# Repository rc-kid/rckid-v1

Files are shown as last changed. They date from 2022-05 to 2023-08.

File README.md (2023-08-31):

# RCkid

Handheld device mostly for kids that works as a retro games player, remote control for lego models and other stuff, walkie talkie, and a simple music/video player. Based on Rpi Zero 2W, ATTiny and NRF24L01P+ with a 320x240 SPI display, a selection of input controls (ABXY, DPAD, Thumbstick, Sel, Start, shoulder buttons, dedicated volume control buttons and a Home button), rumbler, light sensor, RGB torch and a custom software tailored towards the needs of the little ones. 

This is the main repository of the project containing all the necessary information to build the _RCkid_ itself and the remotely controlled devices.

## Overview

The _RCkid_ uses the RPi to run all the user interactive software, libretro via retropie to run emulated old school games and other software. The RPi is connected to digital buttons (ABXY, L, R, Volume) via gpio pins, to the display (`ILI9341`) with `SPI0` and to the NRF Radio via `SPI1`. `I2C` bus connects to the accelerometer, light sensor and the `ATTiny`. 

The `ATTiny` then manages the analog inputs (joystick, voltages, temperatures), multiplexed buttons (Dpad, Select & Start) and the Home/Power button. It is also responsible for the rumbler and the RGB LED as well as charging, battery management and a real-time clock. 

## Developing

> For building the RaspberryPi SD Card image see the [IMAGE.md](sd/IMAGE.md). This section deals with the active development setup. It has been tested on Windows 11, WSL Ubuntu 20. 

    sudo apt-get install vlc alsa-utils
    git clone https://github.com/zduka/rckid-raylib.git
    cd rckid-raylib/src
    make PLATFORM=PLATFORM_DESKTOP
    cd ../..
    git clone https://github.com/zduka/rckid.git
    mkdir rckid/build
    cd rckid/build
    cmake ..

### AVR UPDI Programmer

Serial UPDI is used, more details [here](https://github.com/SpenceKonde/AVR-Guidance/blob/master/UPDI/jtag2updi.md). I am using CH340 based one with a diode (BAT-60J) and internal 1k5 resistor on TX line. 

> Note that when using an adapter with a RX-line LED, such as most CH340 based ones, the LED must be removed or the programmer will *not* work. This is somewhat burried in the original document and it took me a while to realize this. 

There seems to be a possibility of building a high voltage UPDI programmer, details [here](http://www.technoblogy.com/show?48MP).

## Basic Operation

The `fbcp-ili9341` runs in its own process and is responsible for displaying the contents of the framebuffer on the SPI display.

> The display will freeze if someone changes the display properties. This seems to not happen if all apps run as `pi` (no root), but might be investigated further. 

The `rckid` app controls the UI, communicates with the AVR and creates and manages the virtual joystick and keyboard that is used to control the external applications. It uses a patched version of [raylib](https://github.com/zduka/rckid-raylib) that displays the UI at a level that will display itself over the 3rd party apps for videos and games. 

`vlc` and `retroarch` are used for playing videos and games respectively. They are launched by the ui and then controlled via the libevdev virtual gamepad and keyboard. 

- [VideoCore APIs](https://elinux.org/Raspberry_Pi_VideoCore_APIs)
- [DismpanX header](https://github.com/raspberrypi/userland/blob/master/interface/vmcs_host/vc_dispmanx.h)
- [DispmanX example](https://github.com/raspberrypi/firmware/blob/master/opt/vc/src/hello_pi/hello_dispmanx/dispmanx.c)
- [RaspiDMX tools](https://github.com/AndrewFromMelbourne/raspidmx/blob/master/common/imageLayer.c)

### Prepare the RPi image

To build on Raspberry pi, create SD card image according to `sd/IMAGE.md`. This also installs all the prerequisites for building the rpi app and flashing the AVR. 

> As building on rpi is clumsy for development, most of rcboy can be developed on a normal computer (tested on Windows 11 WSL) and then uploaded to the rpi over WiFi. The repository contains tasks and build scripts necessary for such a setup using Visual Studio Code and can be easily adapted to different IDEs/editors.

### Flashing the AVR

When the RCBoy is assembled, the AVR chip is flashed via a custom I2C bootloader (the UPDI voltages would have to be translated otherwise, which is painful as the AVR runs on higher voltage than RPi). The RPi itself can be used to flash the AVR chip before soldered to the board by making a simple UPDI programmer from the serial port. After the bootloader is flashed, the RPi can be soldered to the board and the I2C programmer can be used for future updates. 

### Notes to Self 

- when stuff does not work, double and tripple check that all pins are properly soldered. Obviously no shorts, but weak bonds will result is horrible noise and/or non-functional elements
- a variant of the above, when soldering multiple PCBs together via holes, be extra sure that all PCBs actually have proper contact

## RCKid folder structure

    /rckid
        /music
        /videos
        /games
        /screenshots
        /images
        /recorder
        /saves

# Notes

https://www.flaticon.com/

<div>Icons made by <a href="https://www.flaticon.com/authors/alfredo-hernandez" title="Alfredo Hernandez">Alfredo Hernandez</a> from <a href="https://www.flaticon.com/" title="Flaticon">www.flaticon.com</a></div>
<div>Icons made by <a href="https://www.flaticon.com/authors/pixel-perfect" title="Pixel perfect">Pixel perfect</a> from <a href="https://www.flaticon.com/" title="Flaticon">www.flaticon.com</a></div>
<div>Icons made by <a href="https://www.flaticon.com/authors/vectors-market" title="Vectors Market">Vectors Market</a> from <a href="https://www.flaticon.com/" title="Flaticon">www.flaticon.com</a></div>
<div>Icons made by <a href="https://www.flaticon.com/authors/srip" title="srip">srip</a> from <a href="https://www.flaticon.com/" title="Flaticon">www.flaticon.com</a></div>
<div>Icons made by <a href="https://www.flaticon.com/authors/monkik" title="monkik">monkik</a> from <a href="https://www.flaticon.com/" title="Flaticon">www.flaticon.com</a></div>
<div>Icons made by <a href="https://www.flaticon.com/authors/aldo-cervantes" title="Aldo Cervantes">Aldo Cervantes</a> from <a href="https://www.flaticon.com/" title="Flaticon">www.flaticon.com</a></div>
<div>Icons made by <a href="https://www.freepik.com" title="Freepik">Freepik</a> from <a href="https://www.flaticon.com/" title="Flaticon">www.flaticon.com</a></div>
<div>Icons made by <a href="https://www.flaticon.com/authors/smashicons" title="Smashicons">Smashicons</a> from <a href="https://www.flaticon.com/" title="Flaticon">www.flaticon.com</a></div>
<div>Icons made by <a href="https://www.flaticon.com/authors/umeicon" title="Umeicon">Umeicon</a> from <a href="https://www.flaticon.com/" title="Flaticon">www.flaticon.com</a></div>
<div>Icons made by <a href="https://www.flaticon.com/authors/bukeicon" title="bukeicon">bukeicon</a> from <a href="https://www.flaticon.com/" title="Flaticon">www.flaticon.com</a></div>
<div>Icons made by <a href="https://www.flaticon.com/authors/good-ware" title="Good Ware">Good Ware</a> from <a href="https://www.flaticon.com/" title="Flaticon">www.flaticon.com</a></div>
<div>Icons made by <a href="https://www.flaticon.com/authors/apien" title="apien">apien</a> from <a href="https://www.flaticon.com/" title="Flaticon">www.flaticon.com</a></div>
<div>Icons made by <a href="https://www.flaticon.com/authors/luvdat" title="Luvdat">Luvdat</a> from <a href="https://www.flaticon.com/" title="Flaticon">www.flaticon.com</a></div>
<div>Icons made by <a href="https://www.flaticon.com/authors/surang" title="surang">surang</a> from <a href="https://www.flaticon.com/" title="Flaticon">www.flaticon.com</a></div>
<div>Icons made by <a href="https://www.flaticon.com/authors/chahir" title="chahir">chahir</a> from <a href="https://www.flaticon.com/" title="Flaticon">www.flaticon.com</a></div>

https://www.vecteezy.com/vector-art/4998362-seamless-rainbow-pattern-with-unicorns-hearts-crowns-and-stars-on-a-dark-background

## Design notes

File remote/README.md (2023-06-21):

# RCKid Remote Protocol

A simple and extensible protocol that allows the RCKid to use its onboard NRF radio to remotely control various devices. The RCKid acts as a _remote_ that can control an arbitrary number of _devices_. Each device has a number of _channels_ into which all the device's functionality has to be encoded. The remote protocol supports pairing, querying devices and their channel capabilities and so on. 

> Note that the protocol is very simple and its main purpose is *not* security. 

## Channels

A client device is described by a list of channels. Each channel has a specific type and consists of the following distinct parts:

- _control_, which is information the remote communicates regularly to the device that alters the state of the channel (such as motor speed)
- _feedback_, which is information the device communicates to the remote, such as current consumption
- _config_, which consists of channel configuration that is not expected to be changed once the remote and the device are paired, such as the motor's current limit

Each part of the channel can be empty, depending on the channel type. Channels are identified by numbers from `1` to `255` inclusive. The following channel types are supported:

### Motor channel

The motor channel provides control for single DC brushed motor attached to an H bridge. It consists

### CustomIO

A configurable channel that can fit multiple purposes. Corresponds to a single wire and various digital/analog functions it may have, namely:

Mode              | Control   | Feedback | Config
------------------|-----------|----------| -------------
Digital Out       | 0/1       |          | 00
Digital In        |           | 0/1      | 01
Analog Out (DAC)  | 0 - 255   |          | 02
Analog In (ADC)   |           | 0 - 255  | 03
PWM               | 0 - 255   |          | 04
Servo             | 0 - 65535 |          | 05 iiii xxxx
Tone              | 0 - 65535 |          | 06

### ToneEffect

### RGB Strip

The RGB strip channel is designed to configure and control a strip of RGB colors such as neopixels. The config part of the strip is the index of the first RGB channel specifying the color and the length of the strip. The length of the strip should not exceed the number of RGB colors available. The is no feedback and the channel control is the state of the strip, which can be one of:

ID   | Meaning
-----|-------------------
`00` | Manual control - the strip will display exactly the colors specified in the RGB channels
`..` | Effect - the number specifies which effect to use

### RGB Color

Single RGB color. Its control cosists of the three RGB bytes. No feedback or config is possible. The purpose of the RGB color channel is to simply hold memory for one neopixel. The device itself and the RGBStrip channel's config the determine which of these colors will be used. 

## Communication

## Commands

By default the remote sends the device channel control information and the device sends back the channel feedback info when there is change. Instead of sending directly the channel data, the remote may choose to send one of the predfined commands instead:

`00 00` - Heartbeat

`00 01 xx` - Read feedback of channel `xx`

`00 02 xx` - Read control of channel `xx`

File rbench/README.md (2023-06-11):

# A very simple Raylib benchmark

RPi Zero 2W Legacy:

    Initialized in 88
    Simple frame: 0
    1k textures: 32
    1k text: 81
    1k circles: 195
    1k rectangles: 7
    RT simple frame: 7
    RT 1k textures: 39
    RT 1k text: 80
    RT 1k circles: 210
    RT 1k rectangles: 15

RPi Zero 2W Bullseye:

> This is with X enabled and w/o the fbcp driver

    Initialized in 1326
    Simple frame: 2
    1k textures: 26
    1k text: 20
    1k circles: 38
    1k rectangles: 5
    RT simple frame: 2
    RT 1k textures: 28
    RT 1k text: 27
    RT 1k circles: 39
    RT 1k rectangles: 7

Intel HD630:

    Initialized in 150
    Simple frame: 0
    1k textures: 2
    1k text: 1
    1k circles: 1
    1k rectangles: 0
    RT simple frame: 0
    RT 1k textures: 1
    RT 1k text: 1
    RT 1k circles: 1
    RT 1k rectangles: 0

MESA on WSL SQ3:

    Initialized in 1379
    Simple frame: 3
    1k textures: 44
    1k text: 23
    1k circles: 28
    1k rectangles: 12
    RT simple frame: 2
    RT 1k textures: 43
    RT 1k text: 24
    RT 1k circles: 30
    RT 1k rectangles: 13

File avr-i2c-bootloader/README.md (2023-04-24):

# I2C Bootloader

A simple I2C bootloader that fits in 512 bytes. Both the bootloader and the programmer are pretty specific for the `rckid`, but minimal changes should make them generic. 

## Commands

Each I2C command is a single byte, optionally followed by an argument. The commands are designed in such way that they allow page-by-page writing and reading the memory so that the programmer can write and verify the memory contents with minimal AVR code required. 

`0x00 Reserved`

> Not used for anything. 

`0x01 RESET`

> Resets the chip.

`0x02 INFO`

> Updates the `State` object and sets the buffer address to it so that next reading from the device will return the state object itself. 

`0x03 WRITE_BUFFER`

> Writes data to the buffer. The command is only expected to be used after first setting the buffer address via `SET_ADDRESS` command. Using the flexible set address and the xmega core on Series-X ATTiny chips the same command can be used for writing both flash and eeprom. 

`0x04 WRITE_PAGE`

> Commits the page previously written to the appropriate memory (based on its mapped address). Sets the last error in `Status` info. 

`0x05 SET_ADDRESS`

> The command is followed by a 16bit unsigned which will be the new address for the buffer operations (write/read). By setting the address to the appropriate memory mapped locations for either flash or EEPROM memory the bootloader can simply write both. The same mechanism is also used to retrieve the `Status` object. 

## Bootloader

__Note that the UPDI programmer does not check if the chip is correct. If the chip specified in platformio and the actual chip do not match, the memory writes might not work even if everything else would (different memory will be written due to different page sizes) !!.__ 

The bootloader checks the status of the `AVR_IRQ` pin and if low, enters the bootloader mode. When high (i.e. pull-up enabled on the RPi side) starts the application. The bootloader is protected by a watchdog so that inactivity longer than a second will trigger reboot of the chip. The watchdog is reset after a command receive. 

When the bootloader is busy with a command it signals it by pulling the `AVR_IRQ` low, returning to input state when the command is executed, which allows fast programming times. 

To make programming observable, the bootloader also sets the display brightness to maximum. 

## Programmer

A simple i2c programmer is provided as well. Usage:

    i2c-programmer write HEX_FILE

`HEX_FILE` is path to the Intel HEX file that should be flashed to the chip. By default the programmer must be run by `root` to have access to the I2C and GPIO it requires to communicate with the AVR. The programmer can either time the commands by using the `AVR_IRQ` pin, or it can add a timeout to the commands when the `AVR_IRQ` connection is not available for whatever reason so that the bootloader can be used over I2C entirely. 

> Apart from basic flashing the programmer can do a bit more. Use the `--help` command for list of options. 

## Resources

- https://docs.platformio.org/en/latest/platforms/atmelavr.html#bootloader-programming
- https://www.microchip.com/en-us/application-notes/an2634

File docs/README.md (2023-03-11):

# RCKid Documentation

## MP3 Player / Audio Player

## Walkie-Talkie

The walkie talkie always listens and when a button is pressed reads the mic output and starts sending it immediately. When audio is received, stars playing it immediately. 

## Remote Control

Profiles (!) But how exactly?

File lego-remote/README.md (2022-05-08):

# LEGO Remote Controller for Picoboy

## Pairing

The control brick is very dumb and does not have any internal state (apart from its name) that would survive power cycle, all is managed by the remote. The handshake looks like this:

                              Controller | Remote
                         --------------- | --------------
                                         | L: (listen for new devices - optional) 
    B: broadcast its name on set channel | 
                                         | P1: send pairing info on set channel
                                         | (own name & channel, wait for ACK)
                                         |
            switch channel & wait for P2 | switch to channel, send P2, wait for ACK
                                         |
         (timeout 1 second, return to B) | (timeout 1 second, return to L, or P1)

While pairing the controller flashes red lights. When paired, blue is flashed. Upon pairing the remote uploads the connector profile, after which the pairing is complete. 

While paired the remote periodically updates the controller every 1/100th of a second (10ms). If there is no update for 50ms the controller enters the disconnected state, in which case all motors are powered off and lights flash red. Upon regaining connection, the remote must acknowledge the disconnect before the motors can be powered on again. 

## Power

The controller brick operates from any voltage between 5 and 9 volts, inclusive. It uses a special connector that supports connecting 2 Li-Ion cells in series as well as other configurations:

    1N    2P  
    1N 2N 2P
    1P 1P 2N

Internally the `1P` and `2N` terminals are connected together to provide 7.4V between `1N` and `2P` which should be used for other sources. 

The controller consists of ATTiny, radio and the following:

- 2 motor drivers (5 or 9volts)
- 5 extra peripherals

- motor driver: 2x https://www.pololu.com/product/2960
- 9V stepup: 

## Connectors

The connectors are built from headers, in a way that supports all possible orientations by doubling the pins. 

### Motors

Motors use 3x4 12pin connector that allows the motor to select its own voltage as well as draw voltage for electronics. 

    5V   +   -   9V
    SEL GND GND SEL
    9V   -   +   5V

### I/O

This includes Speaker, RGB lights, buttons... Arranged in 2-1 in a row. 

    5V    X
    GND GND
    X    5V

### Expander

The expander connector is a 7pin 3x2x3 connector with the following layout:

    SDA     SCL
    5V  GND  5V 
    SCL     SDA

> TODO should there be I2C connector? 

## Peripherals

Internally there will be two INA219 for measuring the current on the attached motors. An accelerometer is also a possibility. 

> See if I have enough accels and other useful I2C parts. 

### LEGO 4.5V Motor

Uses the motor connector, 5V input. 

### LEGO Power Functions 9V Motor

Uses the motor connector, 9V input. 

### LEGO NXT Motor 

Uses the motor connector, 9V input. Additionally can use up to 2 peripheral connectors for the speed control. 

- 1 (white) Motor PWR 1
- 2 (black) Motor PWR 2
- 3 (red) GND
- 4 (green) ~4.5V
- 5 (yellow) Encoder 1
- 6 (blue) Encoder 2

### LEGO Compatible servo

Uses the peripheral connector in servo mode. 

### PWM Speaker

Uses a dedicated peripheral connector that is wired to PWM supporting pin. 

### RGB LEDs (chainable)

Uses a peripheral connector

### Button (chainable)

Uses a peripheral connector. Chaining works as or so that any chained button press will register as press.

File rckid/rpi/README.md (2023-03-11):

# Raspberry PI

                           3V3     5V
                I2C SDA -- 2       5V
                I2C SCL -- 3      GND
                AVR_IRQ -- 4*      14 -- UART TX
                           GND     15 -- UART RX
             HEADPHONES -- 17      18 -- BTN_L
                  BTN_R -- 27*    GND
                  BTN_B -- 22*    *23 -- BTN_SELECT 
                           3V3    *24 -- BTN_A
    DISPLAY MOSI (SPI0) -- 10     GND
    DISPLAY MISO (SPI0) -- 9      *25 -- DISPLAY D/C
    DISPLAY SCLK (SPI0) -- 11       8 -- DISPLAY CE (SPI0 CE0)
                           GND      7 -- DISPLAY RESET (SPI0 CE1)
                  BTN_X -- 0        1 -- BTN_START
               NRF_RXTX -- 5*     GND
                NRF_IRQ -- 6*      12 -- AUDIO L
                AUDIO R -- 13     GND
              SPI1 MISO -- 19      16 -- SPI1 CE0
                  BTN_Y -- 26      20 -- SPI1 MOSI
                           GND     21 -- SPI1 SCLK

# Setup

To run locally in WSL, when starting `XLaunch` make sure that _Native opengl_ is disabled and then run the following before the app:

    export LIBGL_ALWAYS_INDIRECT=0

That should make raylib happy. 

## Building raylib on RPi

The cmake build is broken, run using the [wiki](https://github.com/raysan5/raylib/wiki/Working-on-Raspberry-Pi), i.e. `-PLATFORM=RPI` being told to make. 

> Note that raylib is expected to live next to rckid

## App

### Status Bar

- time, wifi, nrf, battery (charging), volume

### Bottom Help

- here just show what buttons do what action

https://www.raylib.com/cheatsheet/cheatsheet.html

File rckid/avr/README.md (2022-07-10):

# ATTiny1616 Code

The ATTiny is always-on, responsible for analog user input, the volume buttons (which are also used to turn the device on) and some other inputs and outputs. 

> See the `src/avr.cpp` file for more details. 

## Overview

## Pinout

                   -- VDD             GND --
           AVR_IRQ -- (00) PA4   PA3 (16) -- VIB_EN
         BACKLIGHT -- (01) PA5   PA2 (15) -- CHARGE
            RGB_EN -- (02) PA6   PA1 (14) -- BTN_LVOL
             VBATT -- (03) PA7   PA0 (17) -- UPDI
          PHOTORES -- (04) PB5   PC3 (13) -- RGB
           MIC_OUT -- (05) PB4   PC2 (12) -- JOY_V
          BTN_RVOL -- (06) PB3   PC1 (11) -- JOY_BTN
            RPI_EN -- (07) PB2   PC0 (10) -- JOY_H
         SDA (I2C) -- (08) PB1   PB0 (09) -- SCL (I2C)

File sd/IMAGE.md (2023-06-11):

# SD Image Setup

> TODO provide a download of the full rpi image as part of the project with all this setup. Follow this windowde only when building new image. 

Download RaspberryPi OS Imager and select the Retropie distribution for Raspberry pi 2 W. Flash the image on the SD card and then reinsert the card. Its `boot` partition will be mounted. Edit the default networks the RPI should connect to in the `sd/wpa_supplicant.conf` (higher priority is better). Then copy the `wpa_supplicant.conf` and `ssh` files from the `sd` directory to the boot partition on the SD card. Insert the card to rpi and power on. 

> The extra settings dialog accessible with `c-s-X` does not seem to actually do anything, which is why the above steps are done manually. (Manual settings from [here][https://retropie.org.uk/docs/Wifi/])

To connect to the board, determine its ip address and ssh with username `pi` and password `raspberry`. 

Then run the following:

    git clone git@github.com:zduka/rckid.git

Then run `sudo raspi-config`, enable audio jack audio and i2c, disable the experimental gl driver. 

To configure _retropie_, run the following:

    sudo ~/RetroPie-Setup/retropie_setup.sh

Install `dosbox`, `lr-vice`, `cannonball` and `opentyrian`. 

When done, run the rest of the SD image setup (see the script file for details):

    cd rckid
    bash sd/install.sh

Then run `sudo raspi-config` and make the following changes:

- disable wait for the network during boot
- disable tty on serial console
- set audio output to headphones

# Startup Time

To analyze startup time run the following commands for the overall time, for the longest hogs and for a pretty plot:

    systemd-analyze
    systemd-analyze blame
    systemd-analyze plot > plot.svg

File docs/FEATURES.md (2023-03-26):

# RCKid Features

> A draft of the features of the system. Work in progress, very rough. 

## Powering On

Long press of the _Home_ button initiates the power-on sequence of the device. Press the _Home_ button down and hold it until the device rumbles for start. After the button is pressed, RCKid runs internal diagnostics and the following outcomes, signalled by the rumbler and/or the RGB are possible:

RGB     | Rumbler | Description
--------|---------|-------------
none    | none    | Normal startup sequence, no errors detected. Wait for the rumbler's ok signal to release the _home_ button. 
3 x red | none    | Critical battery level. RCKid will not start, connect charger to the USB-C port and recharge the battery.
blue    | none    | Attempting to power on normally, but last power down timed out. 
green   | none    | Immediate power on retry after the RPi failed to boot in time previous. 2 retries will be attempted with progressively longer boot timeouts. If all are unsuccessful, the device enters the repair mode. 
1x red  | fail    | Device is in repair mode, but not connected to the charger. Connect to the charger and start again to start RCKid in repair mode. 
red     | none    | Device starts in repair mode. Must be connected to the charger. 

## Repair Mode

The repair mode is activated when the AVR is unable to wake up the Rpi and therefore RCKid cannot resume normal operation. During the repair mode the timeouts are disabled and the RPi is constantly powered so that debugging it can be enabled. 

## Controls

- when either of the volume buttons are pressed, they control the volume (with repeat mode on)
- when both are pressed we enter the admin menu. This gives the delay too

## Main Menu

- play games from retroarch
- play music stored in playlists
- play videos stored in playlists
- walkie-talkie
- remote control

## Control Menu

Control menu is reached by long pressing volume up and volume down simultaneously. It consists of the following items:

- power off
- airplane mode
- torchlight
- baby monitor
- settings

## Settings

- brightness (then a progress bar) 
- volume (then a progress bar)
- wifi (then selection of networks to try to connect to + own AP)
- informaton (extra info about wifi, connecting, etc.)

When in the control menu, the header displays the details (battery capacity in pct, connected wifi network, etc.)

## Playging Games

Various libretro cores and games can be played. Optimized for kids, i.e. you select games, not cores. 

> Should games be organized in playlists?

## Playing Music

Ideally do this from within the app so that we can keep control of the screen. Organized in playlists. 

## Playing Video

Also ideally play from within the app so that we can regain control. Organized in playlists. 

## Walkie Talkie

A simple push to talk radio using the nrf chip onboard.

> If there is no-one within reach, the radio can switch to telegram mode and start pushing to telegram if wifi is enabled?

## Remote Control

A remote control app that uses the NRF radio. Different profiles may be chosen and configured from within the app. 

> Need to determine the API for the remote control, feedback, etc. 

## Torchlight

Simple torchlight with extra functions, such s blinking, colors, etc. 

> Is this part of the main menu, or the advanced menu with power off? 

# Extra features

- allow time budgets for different activities? Allow topping up the budgets by parents and so on? 
- tamagotchi? 
- web server for more advanced settings & control by parents? 
- customizable easter eggs for the kids? 

# Very extra features

- libretro multiplayer via nrf or some other means

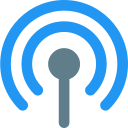
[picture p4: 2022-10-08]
assets/images/017-signal.png

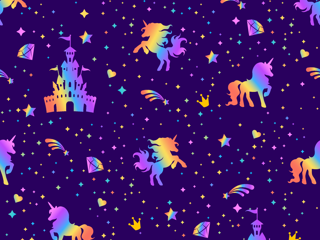
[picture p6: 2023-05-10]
assets/backgrounds/unicorns.png

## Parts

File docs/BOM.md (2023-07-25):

# RcKid

Part            | #  | Stock | Notes & URL
----------------|----|-------|----------------------------------------------------------------------------
MPU6050         | 1  | 3     | https://www.laskakit.cz/open-smart-gyroskop-s-akcelerometrem--mpu6050--i2c--6-axis/
USB-C breakout  | 1  | 3     | https://cz.mouser.com/ProductDetail/Adafruit/4090?qs=2WXlatMagcFDROXrdbBXdg%3D%3D
Rumbler         | 1  | 3     | https://cz.mouser.com/ProductDetail/474-ROB-08449
E01-2G4M27D     | 1  | 3     | https://www.laskakit.cz/bezdratovy-modul-e01-2g4m27d--nrf24l01--2-4ghz-long-range/
Antenna         | 1  | 1   ! |
M2.5 Insert     | 4  | 15    | 
J1 (headphones) | 1  | 4     | https://www.mouser.co.uk/ProductDetail/CUI-Devices/SJ-43504-SMT-TR?qs=WyjlAZoYn519xUgky5FVDA%3D%3D
Battery         | 1  | 3     | https://www.laskakit.cz/baterie-li-po-3-7v-3000mah-lipo/
Battery Conn    | 1  | 3   ! | https://cz.mouser.com/ProductDetail/Adafruit/1769?qs=GURawfaeGuBbgoGtf2XstA%3D%3D
M1.4 Insert     | 2  | 10    |
Button (soft)   | 10 | 39    | https://cz.mouser.com/ProductDetail/667-EVP-BFAC1A000
Button (slim)   | 3  | 0   ! | https://cz.mouser.com/ProductDetail/667-EVQ-Q2P02W
ATTiny 1616     | 1  | 42    | https://cz.mouser.com/ProductDetail/Microchip-Technology-Atmel/ATTINY1616-SN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
RPi Zero 2W     | 1  | 4     |
ILI9341         | 1  | 2   ! | 3.2", SPI interface, https://www.aliexpress.com/item/32861524235.html?spm=a2g0o.order_list.0.0.21ef1802FIsxYt
Microphone      | 1  | 5     | https://cz.mouser.com/ProductDetail/490-CMEJ-0415-42-P
MAX9814         | 1  | 3     |
SMT Rpi Hdr     | 1  | 3     |
Switching 3v3   | 1  | 4     | Adafruit 3V3 Switching regulator, https://cz.mouser.com/ProductDetail/Adafruit/4711?qs=DPoM0jnrROXfrzBVynOxwA%3D%3D
Speaker         | 1  | 1   ! | https://cz.mouser.com/ProductDetail/490-CES-2704088L050A
VEML7700T       | 1  | 2   ! | https://cz.mouser.com/ProductDetail/78-VEML7700-TT
DM1045u         | 4  | 100   | 
FDV303N         | 1  | 7     | Switching MOSFET-N
4u7 (0805)      | 3  | 14    | C1, C4, C6
1u (0805)       | 7  | >30   | C2, C3, C10, C20, C22, C26, C27
100u (1206)     | 2  | 8     | C5, C27 (can be 220u as well - have 2))
220p (0805)     | 2  | 8     | C8, C15
47u (0805)      | 1  | 6     | C9
100n (0805)     | 6  | >30   | C12, C13, C14, C16, C17, C24
10u (0805)      | 3  | >20   | C19, C23, C25
1M              | 1  | 9     | R1
10K             | 7  | >30   | R2, R3, R4, R5, R6, R23, R34
2k5             | 1  | >10   | R7
100k            | 2  | >20   | R8, R13
100R            | 9  | >30   | R10, R11, R14, R15, R17, R20, R21, R24, R33
0R              | 1  | 28    | R16
470R            | 2  | >10   | R18, R19
1k              | 1  | >20   | R22
22R             | 1  |     ! | R27
1k8             | 2  | >10   | R28, R29
10R             | 1  | 7     | R31
3k3             | 2  | 10    | R35, R40
5k6             | 2  | 10    | R36, R41
2k2             | 2  | 9     | R37, R38
100uH           | 1  | 6     | L1, https://cz.mouser.com/ProductDetail/810-VLCF4020T101MR26
Ferrite Bead    | 2  | 8     | L2, L3 
TPS7A2030PDBVR  | 1  | 9     | IC1, 3V LDO
MCP73831T       | 1  | 10    | IC2, Li-Ion battery charger, https://www.mouser.co.uk/ProductDetail/Microchip-Technology/MCP73831T-2ACI-OT?qs=yUQqVecv4qvbBQBGbHx0Mw%3D%3D
SN74LVC2G17DBVT | 1  | 5     | IC3, Schmitt Trigger, https://www.mouser.co.uk/ProductDetail/Texas-Instruments/SN74LVC2G17DBVT?qs=pajgIaoyDUjxtZSztFA6UQ%3D%3D
74LVC1G04W5     | 1  | 5     | IC4, Inverter, https://cz.mouser.com/ProductDetail/Diodes-Incorporated/74LVC1G04W5-7?qs=8Dv1RiiPiVJr3C1LRLmsKw%3D%3D
PAM8302         | 1  | 10    | IC5, D Class Amplifier, SOIC, https://cz.farnell.com/diodes-inc/pam8302aadcr/audio-power-amp-d-40-to-85deg/dp/3373818?st=pam8302
Schott 2A 1206  | 2  | >20   | D1, D3,  https://cz.mouser.com/ProductDetail/581-SD1206S040S2R0
DF2B7AFUH3F     | 1  | 9     | D2, anti-static protection diode

# LegoRemote

Part            | #  | Stock | Notes & URL
----------------|----|-------|----------------------------------------------------------------------------
INA219BIDR      | 3  | 12    |
2x3 straight    | 9  | 29    |
2x3 righta      | 10 |     ! |
2x4 straight    | 1  | 5     |
8m              | 1  |     ! |  
4m              | 2  |     ! |
U3V40F9         | 1  | 2     | 9V Step-Up module (Pololu)
BD65496MUV      | 2  | 4     | H-Bridge

D1              | 1  | 25 | Schottky diode 2A 1206, https://cz.mouser.com/ProductDetail/581-SD1206S040S2R0
D2              | 1  | 10 | Schottky diode 0.5A 0805, https://cz.mouser.com/ProductDetail/581-SD0805S040S0R5
MCP6401         | 1  | 10 | opamp, 
74LVC1G04W5-7   | 1  | 8  | inverter SOT-23-5, https://cz.mouser.com/ProductDetail/Diodes-Incorporated/74LVC1G04W5-7?qs=8Dv1RiiPiVJr3C1LRLmsKw%3D%3D
MIC5504         | 1  | 22 | 3v3 LDO, https://www.mouser.co.uk/ProductDetail/Microchip-Technology-Micrel/MIC5504-33YM5-TR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
JOY             | 1  | 5  | Nintendo Switch Thumbstick replacement
JOY-Header      | 1  | 10 | 5pin FPC, contants top, https://cz.mouser.com/ProductDetail/649-SFV5R-2STE1HLF
Ferrite Bead  ! | 2  | 6  | https://cz.mouser.com/ProductDetail/710-742792092

> + resistor divider on PAM8302 input for volume, has to be calculated 

# LegoRemote

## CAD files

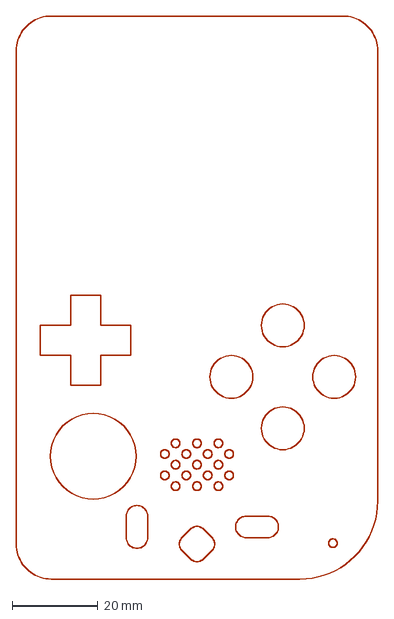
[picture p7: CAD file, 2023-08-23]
hardware/rckid-top-plate.dxf
84.3 x 131.3 mm

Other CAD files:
hardware/rckid.skp

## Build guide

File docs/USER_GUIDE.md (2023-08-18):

> This guide assumes that you have already followed the assembly guide and have a working RCKid at your disposal. 

# RCKid Simple Manual

## Powering Up and Down

To start the device, press and hold the _Home_ button until the rumbler's _ok_ signal (one long rumble), after which the button can be released. Then wait for the device to boot and turn the screen on. 

To power down, navigate the menu to the home section and select the _Power off_ option. This is usually done by pressing the _Home_ button once, or twice when playing a game. 

Alternatively, holding the _Home_ button down util the rumbler's _ok_ signal is given will instruct the RPi to power itself off as well. 

## Charging

RCKid can be charged by any USB-C capable charger. For increased safety, the charging is rather slow. The device can be on while charging. If on, charging status is displayed in the header bar. When off, the RGB led displays charging status, _blue_ light means the device is charging, _green_ light means RCKid is fully charged. 

## Troubleshotting

### Initial Power Up

When power is first applied to the device (be it from attached battery, or USB), the device will power on automatically.  

### Critical Battery

Rumbler's _fail_ signal and 3 bright red LED flashes indicate critical battery level upon power on. Plug the device into USB to to recharge the battery and start again. 

### Power On Failure

If the screen stays black after powering on and in a while the rumbler's _fail_ and red led is displayed, the RPi failed to turn on in time. This could be one-time event, or might require deeper debugging using the forced-on mode. 

### Power Off Failure

If a rumbler _fail_ and red LED is displayed after powering the device off, the RPi failed to signal safe shutdown in time. The device is now off.  

### Forced on mode

Powering the device on with _Home_ and _Select_ buttons both pressed until the _ok_ rumbler signal will enable a forced on mode, in which case the brightness is immediately turned on and all power-on timeouts are disabled so that the state of the device on display can be observed.

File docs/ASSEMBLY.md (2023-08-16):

# Assembly

Please note that building _RCKid_ is likely not a beginner project. At the very least, you will need access to a soldering station and some soldering practice. If there will be any errors during the assembly, multimeter, oscilloscope and some basic electronics knowledge would be required. Some software skills, such as SSH connection and flashing is necessary as well. 

## PCB

Have the PCB printed. Simple 2 layer stackup is used with relatively large tolerances. Use either the [diptrace project](../hardware/rckid.dip) itself, or the [gerber files](../hardware/rckid.zip) that are part of this repository. The board thickness is expected to be 1.6mm. 

> I do recommend [aisler](https://aisler.net) if your are in Europe. 

Break out the small left and right trigger button PCBs located at the top of the board, sand any rough edges from mousebites and ensure the joystick fits through the joystick hole, sanding the round corners from milling to right angles. 

### Accelerometer

> Accelerometer is optional. 

Sand the rounded edges of the accelerometer hole to right angles to ensure accelerometer fit. Then press the accelerometer in with its components on the bottom side. Ensure the bottom side of the accelerometer pcb lines up perfectly with the top side of the RCKid pcb. Then cover from the top side with kapton tape, flip RCKid pcb so that you can see the bottom side (with accel components now visible) and solder the accelerometer in the castellated holes provided on both sides. 

### Top-side PCB components

Flip the RCKid so that the top side is visible (with logo & display connector) and solder all items except the display, microphone module and the 3V3 module for the radio. 

### 3V3 Buck Converter

Trip the module to the required size by making the pin holes into castellations and cutting the top piece roughly in the middle of the mounting hole. Then solder to place. 

### Basic tests

Do the following basic tests to ensure the board is in good condtition:

- verify that GND and VCC / VBATT is not shorted
- connect 5V power to the USB-C breakout pins (the breakout itself is not yet soldered) and verify the voltages at RPi, AVR, NRF radio and the 3V clean LDO for microphone and audio

### AVR Bootloader

Solder the downward facing precission sockets for the GND and UPDI programming and then program the AVR's bootloader. Make sure to connect the GND first (!). 

> You can use either a dedicated UPDI programmer (a detailed description of how to make one can be found [here]())  

## Soldering PCB 

## Instructions

1) File the pcb to ensure that all holes are proper sizes and ensure components do fit.  
2) Solder the accelerometer, components facing down, the bottom side of the accelerometer breakout should be level with the top side of RCKid's pcb. 

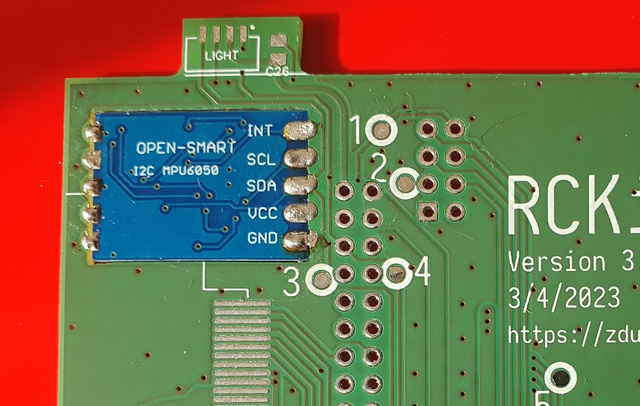
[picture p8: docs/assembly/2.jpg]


#### USB Power & Battery Charging

3) Solder the USB & battery power bridge (R3, D1, Q2, C27). 

> Verify VCC (via C24 & C25) via either the USB or BATT+ pins (leave the battery connector disconnected yet)

4) Solder the battery charging circuit (D2, C1, C4, IC2, R7, R2, R6). 

#### RPI & RGB Power Switches

5) Add the RPI power switch (R1, Q1)

> Verify VRPI (6) when power applied

6) Add the RGB power switch (R4, R27, Q3)

#### VCLEAN for Audio

7) Add VCLEAN LDO (L1, IC1, C2, C3)

> Check that VCLEAN (30) is 3V

#### ATTiny1616

8) Add ATTiny and its capacitors (ATTINY, C24, C25)
9) Program ATTiny bootloader & fuses via the UPDI (27)

#### 

First we are going to add the `ATTiny1616` and basic `I2C` communication to program the bootloader and verify its presence. To do so, the following must be soldered:

> TODO

When the bootloader is flashed, verify that the `I2C` communication is working by running the AVR programmer in query mode. 

## Powering Up

To power up attach the (ideally pre-charged) battery and optionally the USB-C charger as well. Upon power-on the AVR chip enters the power-on sequence

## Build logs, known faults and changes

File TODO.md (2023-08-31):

Have saved states for mgba. the trick is to put the .so of the cores to the same dir as the info files. 
- move this to my own folder for the cores we support
- do auto save before leaving the game (and renaming of the saved states and stuff)

> This is the high-level plan on tasks, prioritized, to make the RCKid ready for xmas:

- design the bottom and top frames around the pcb and test print the stack
- add rckid basics (proper header, hearts & configuration and settings)
- print ASA enclosures - ASA samples from here (it actually glows in the dark even): https://www.na3d.cz/p/2621/vzorek-fiber3d-asa-svitici-ve-tme-175-mm-10-m?variant[117]=1071
- test build the assembly
- test walkie talkie, add beeps

> At this point, I'll have a barebones, but working rckid that can play some games, play music & video and act as walkie talkie. This can be presented as xmas gift. Then there are two things I can do:

- fix lego remote schematics & pcb layout
- build
- add remote controller to rckid
- build rc car from lego

> or I can focus on improvements to the user stuff, such as:

- reoreding and renaming elements in menus
- icon selector, video & game still captures
- game savepoits
- alarm / other niceties
- telegram configuration
- samba
- wifi settings

- order plexiglass covers (https://plasticexpress.cz/)

# Things to check

- battery on: 9:30
- charging: 9:45 - 11:22

> Currently in progress/working on. All projects combined. When removing from here make sure to check the sections below for long term items and remove them as needed. 

https://plasticexpress.cz/configurator/1-plexisklo-ir-/2-extrudovan-/3-1-5-mm

- change icon can be done by having all images under one root and that way items can be selected from the pics easily
- rename via keyboard ofc

- allow configurable item action for items (not folders)

- repairing after connection lost does not work (channel & name is different) Add a pairing timeout on the device and wait for pairing indefinitely on the rckid side

> Things to buy / test. 

## Shopping List

- buy some more NRFs (not the cheapest ones)
- https://martybugs.net/wireless/rubberducky.cgi -- site that seems to have decent info on antennas
- better 3.0V LDO (cleaner, higher voltage better for mic & speed, such as https://cz.mouser.com/ProductDetail/Texas-Instruments/TPS7A2030PDBVR?qs=hd1VzrDQEGgZMtQinkbhYw%3D%3D)
- buy extra RPi Zero 2W's (2-3), that way I have parts to build almost 6 RCKids (modulo joysticks)

> TODOs for the various projects that RCkid consists of. Each project has its own todo list.

## RCKid PCB & Case

- make the bottom taller to remove the 0.1mm gap between top and bottom pieces
- make them lock better together, maybe bottom smaller to fit nicely in the case
- can the PCB with joystick soldered on be slided into the case? 
- enlarge the headphone jack a bit
- move USB port a bit higher
- center the light's hole better
- maybe go all the way top/bottom with transparent ribbon for better visibility? 
- is the joystick centered? 

## RCKid AVR

- add LED effects
- rumbler effects

## RCKid RPi

- game player menu implementation (load/save, etc.)
- torchlight widget (?)
- walkie talkie widget
- photores

## RCKid RPi - SDCard

- ensure config on fresh start from clean sd
- disable serial port
- would it make sense to use fewer cores at higher speed? 
- turn off/stuff - https://github.com/raspberrypi/firmware/blob/13691cee95902d76bc88a3f658abeb37b3c90b03/boot/overlays/README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, map to one of the UART pins 
- can we speed things up with crosscompilation? https://deardevices.com/2019/04/18/how-to-crosscompile-raspi/

## LEGO Remote PCB & Case

- how to do charging (?)

## LEGO Remote AVR

- check motor control
- check analog input
- PWM motor control frequency - 20kHz should be enough
- add INA219 - how will INA be connected to the stuff? - DeviceInfoChannel? 
- remember last pairing information? how to remove it? 
- make batteries into separate brick, makes the design so much simpler I might actually make the xmas deadline

> Non-critical things that would be nice to have, but don't jeopardize the xmas delivery. 

## I2C Bootloader

- cleanup & extend the programmer code so that it can dump the stored files, read/write EEPROM and so on

## RCKid

- walkie & talkie with telegram enabled
- recorder app
- piano app> (but how to do keys?)
- Baby monitor app (MIC threshold wakeup levels on AVR, app on RPi)

- add == to Value and double parsing
- add JSON ostream << for array and struct
- add JSON backed menu that allows reordering
- how to configure, via JSON I guess,
- samba on demand? etc.
- webserver from the app - see https://github.com/yhirose/cpp-httplib ?
- telegram remote control 

- allow games to set the accelerometer or joystick as different buttons

## Raylib 

- the GPU performance is well... bad. 
- check if using VCDispmanX, or SDL can improve things. 
- check that we are find detecting first boot with it

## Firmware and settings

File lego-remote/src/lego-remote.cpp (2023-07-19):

#define DEBUG_OLED


#include "platform/platform.h"
#include "platform/peripherals/nrf24l01.h"
#include "platform/peripherals/neopixel.h"
#include "platform/peripherals/ina219.h"
#ifdef DEBUG_OLED
#include "platform/peripherals/ssd1306.h"
#endif

#include "remote/lego_remote.h"
/** Sets the connection timeout interval after which the motors turn off. Expressed in 64ths of a second. 
 */
#define CONNECTION_TIMEOUT 32  

/** In 1/4 of second. 
 */
#define CONNECTION_RESET 120

using namespace platform;
using namespace remote;

template<typename CHANNEL> struct Channel {
    typename CHANNEL::Config config;
    typename CHANNEL::Control control;
}; // Channel

/** LEGO Remote
 
    A remote controller to be used mainly with lego. Supports DC motors at 5 or 9V, servo motors, PWM channels, digital and analog inputs, neopixels and tones. 

                     -- VDD             GND --
           ML1 (WOA) -- (00) PA4   PA3 (16) -- SCK
           MR1 (WOB) -- (01) PA5   PA2 (15) -- MISO
              NRF_CS -- (02) PA6   PA1 (14) -- MOSI
            NRF_RXTX -- (03) PA7   PA0 (17) -- UPDI
    XL1 (WO2*, A0-8) -- (04) PB5   PC3 (13) -- XR1 (WO3*, A1-9)
    XL2 (WO1*, A0-9) -- (05) PB4   PC2 (12) -- XR2 (lcmp0, A1-8) -- use interrupt for waveform
             NRF_IRQ -- (06) PB3   PC1 (11) -- MR2(WOD)
        NEOPIXEL_PIN -- (07) PB2   PC0 (10) -- ML2(WOC)
                 SDA -- (08) PB1   PB0 (09) -- SCL

    Motor Channels

    2 motor channels (ML and MR) are supported. Each channel controls a single DC motor with two PWM pins for CW and CCW operation in 64 speed steps and braking & coasting. TCD is used to drive the motors' PWM signals. The motor channels use 3x4 pin connectors where the connector can select whether the pin will use 5V or 9V. The connectors can be inserted either way and have the following pinout:

        5V   +   -   9V
        SEL GND GND SEL
        9V   -   +   5V

    Configurable Channels

    4 extra channels are provided, XL1, XL2 and XR1 and XR2. The channels use a 2x3 connector that provides 5V, GND and one pin that can be configured as either of:

    - digital input
    - analog input (ADC)
    - digital output
    - analog output (PWM)

    Timers

    - 20ms intervals for the servo control (RTC)
    - 2.5ms interval for the servo control pulse (TCB0)
    - 2 8bit timers in TCA split mode
    - 1 16bit timer in TCB1 




    - RTC is used for delays
    - TCD is used for motors exclusively
    - TCB1 is used for precise servo control timing
    - TCA0 in split mode is used for the PWM channels (2 extra pins left) -- some positioned directly
    - TCB0 for tone generation (so that we can use arduino's tone function by default)

    - maye have the tone generator repurpose customIOs w/o tone stuff in the custom (i.e. mark it as out)

 */
class Remote {
public:

    static constexpr gpio::Pin NEOPIXEL_PIN = 7; 

    static constexpr gpio::Pin ML1_PIN = 0; // TCD, WOA
    static constexpr gpio::Pin MR1_PIN = 1; // TCD, WOB
    static constexpr gpio::Pin ML2_PIN = 10; // TCD, WOC
    static constexpr gpio::Pin MR2_PIN = 11; // TCD, WOD

    static constexpr gpio::Pin L1_PIN = 4; // PB5, ADC0-8, TCA-WO2* (low channel 2)
    static constexpr gpio::Pin L2_PIN = 5; // PB4, ADC0-9, TCA-WO1* (low channel 1)
    static constexpr gpio::Pin R1_PIN = 13; // PC3, ADC1-9, TCA-W03* (high channel 0)
    static constexpr gpio::Pin R2_PIN = 12; // PC2, ADC1-8, uses TCA-W0 (low channel 0) cmp and ovf interrupt to drive the pin

    static constexpr gpio::Pin NRF_CS_PIN = 2;
    static constexpr gpio::Pin NRF_RXTX_PIN = 3;
    static constexpr gpio::Pin NRF_IRQ_PIN = 6;

    static inline uint8_t rtcTicks_ = 0;

    static void initialize() {
        // set CLK_PER prescaler to 2, i.e. 10Mhz, which is the maximum the chip supports at voltages as low as 3.3V
        CCP = CCP_IOREG_gc;
        CLKCTRL.MCLKCTRLB = CLKCTRL_PEN_bm; 
        gpio::initialize();

        // clear all RGB colors, set the control LED to green & update
        gpio::output(NEOPIXEL_PIN);
        rgbColors_.clear();
        rgbColors_[0] = Color::White();
        rgbColors_.update();

        i2c::initializeMaster();
        spi::initialize();

        // set configurable channel pins to input 
        gpio::input(L1_PIN);
        gpio::input(L2_PIN);
        gpio::input(R1_PIN);
        gpio::input(R2_PIN);
        // ensure motor pins output low so that any connected motors are floating
        gpio::output(ML1_PIN);
        gpio::low(ML1_PIN);
        gpio::output(ML2_PIN);
        gpio::low(ML2_PIN);
        gpio::output(MR1_PIN);
        gpio::low(MR1_PIN);
        gpio::output(MR2_PIN);
        gpio::low(MR2_PIN);

        initializeMotorControl();
        initializeServoControl();
        initializeAnalogInputs();
        initializePWMOutputs();
        initializeAudio();
        initializePowerManagement();
#ifdef DEBUG_OLED
        initializeDebug();
#endif

        // initialize the effects timer of 64Hz (15.6ms) for RGB & tone switches
        RTC.CLKSEL = RTC_CLKSEL_INT32K_gc;
        RTC.PITCTRLA = RTC_PERIOD_CYC32_gc | RTC_PITEN_bm;
        // TODO also use this to ensure that we have a connection with the controller and turn off motors & stuff if we don't 

        

        // initialize the NRF radio
        if (!initializeRadio()) {
            rgbColors_[0] = Color::Red();
            rgbColors_.update();
            while (true) {}
        }

        // turn the white color off to signify we are done with startup
        rgbColors_.clear();
        rgbColors_.update();

        // TODO delete this when ready
        setChannelConfig(LegoRemote::CHANNEL_L1, (uint8_t*) & channel::CustomIO::Config::output());
        setChannelConfig(LegoRemote::CHANNEL_L2, (uint8_t*) & channel::CustomIO::Config::inputPullup());
        setChannelConfig(LegoRemote::CHANNEL_TONE_EFFECT, (uint8_t*) & channel::ToneEffect::Config{LegoRemote::CHANNEL_L1});
        startToneEffect(& channel::ToneEffect::Control::yelp(600, 1200, 1500));
    }

    static void loop() {
        checkDigitalIn();
        checkAnalogIn();
        servoTick();
        if (gpio::read(NRF_IRQ_PIN) == 0)
            radioIrq();
        if (RTC.PITINTFLAGS == RTC_PI_bm) {
            RTC.PITINTFLAGS = RTC_PI_bm;
            ++rtcTicks_;
            // send the delayed response
            if (responseTimeout_ > 0 && --responseTimeout_ == 0) 
                radioResponse();
            if (rtcTicks_ % 16 == 0) { // 64Hz fo effects, power and connection timeouts
                // check the power settings 
                checkPower();
                if (connTimeout_ > 0) {
                    if (connected()) {
                        if (rtcTicks_ % 10 == 0 && --connTimeout_ == 0)
                            connectionLost();
                    } else {
                        if (rtcTicks_ == 0 && --connTimeout_ == 0)
                            cpu::reset();
                    }
                }
                // do tone effect if any
                toneEffectTick();
                // do rgb effect, if any 
                rgbEffectTick();
            }
            
#ifdef DEBUG_OLED
            if (rtcTicks_ == 0 && (++dbgTimeout_ % 4) ==0) // 1Hz
                debugPrint();
#endif
        }
   
    }

#ifdef DEBUG_OLED
    /** \name Debug I2C display 
     
        Displays the messages 
     */
    //@{
    static inline SSD1306 oled_;
    static inline uint8_t dbgTimeout_ = 0;
    static inline uint16_t rx_ = 0;
    static inline uint16_t tx_ = 0;
    static inline uint16_t errors_ = 0;

    static void initializeDebug() {
        oled_.initialize128x32();
        oled_.normalMode();
        oled_.clear32();
        oled_.write(0, 0, "RX:");
        oled_.write(64, 0, "TX:");

        oled_.write(0, 1, "ML:");
        oled_.write(0, 2, "L1:");
        oled_.write(0, 3, "L2:");
        oled_.write(64, 1, "MR:");
        oled_.write(64, 2, "R1:");
        oled_.write(64, 3, "R2:");
    }

    /* */
    static void debugPrint() {
        if (paired()) {
            debugMotor(20, 1, ml_);
            debugMotor(84, 1, mr_);
            debugCustomIOChannel(20, 2, l1_.config, l1_.control, feedback_.l1);
            debugCustomIOChannel(20, 3, l2_.config, l2_.control, feedback_.l2);
            debugCustomIOChannel(84, 2, r1_.config, r1_.control, feedback_.r1);
            debugCustomIOChannel(84, 3, r2_.config, r2_.control, feedback_.r2);
            oled_.write(20, 0, rx_);
            oled_.write(84, 0, tx_);
        } else {
            char x[6] = { 0,0,0,0,0,0};
            radio_.txAddress(x);
            oled_.write(0, 1, x);
            radio_.rxAddress(x);
            oled_.write(0, 2, x);
            oled_.write(20, 0, rx_);
            oled_.write(84, 0, tx_);
        }
    }

    static void debugMotor(uint8_t x, uint8_t y, Channel<channel::Motor> & m) {
        switch (m.control.mode) {
            case channel::Motor::Mode::Coast:
                oled_.write(x, y, "coast ");
                break;
            case channel::Motor::Mode::Brake:
                oled_.write(x, y, "brake ");
                break;
            case channel::Motor::Mode::CW:
                oled_.write(x, y, "cw     ");
                oled_.write(x + 20, y, m.control.speed);
                break;
            case channel::Motor::Mode::CCW:
                oled_.write(x, y, "ccw    ");
                oled_.write(x + 20, y, m.control.speed);
                break;
        }
    }

    static void debugCustomIOChannel(uint8_t x, uint8_t y, channel::CustomIO::Config & config, channel::CustomIO::Control & control, channel::CustomIO::Feedback & feedback) {
        switch (config.mode) {
            case channel::CustomIO::Mode::DigitalIn:
               oled_.write(x, y, "di     ");
               oled_.write(x + 20, y, feedback.value);
               break;
            case channel::CustomIO::Mode::DigitalOut:
               oled_.write(x, y, "do     ");
               oled_.write(x + 20, y, control.value);
               break;
            case channel::CustomIO::Mode::AnalogIn:
               oled_.write(x, y, "ai     ");
               oled_.write(x + 20, y, feedback.value);
               break;
            case channel::CustomIO::Mode::PWM:
               oled_.write(x, y, "pwm     ");
               oled_.write(x + 20, y, control.value);
               break;
            case channel::CustomIO::Mode::Servo:
               oled_.write(x, y, "pwm     ");
               oled_.write(x + 20, y, control.value);
               break;
        }
    }

    //@}
#endif

    /** \name Power Management 
     */
    //@{

    static inline INA219 iSenseTotal_{0x40};
    static inline INA219 iSenseML_{0x44};
    static inline INA219 iSenseMR_{0x45};

    static void initializePowerManagement() {
        // 8mOhm for 10Amps max resolution in mA
        iSenseTotal_.initialize(INA219::Gain::mv_80, 8);
        /*
        // for the motors, we take 4mOhms for 5Amps max resolution
        iSenseML_.initialize(INA219::Gain::mv_80, 4);
        iSenseMR_.initialize(INA219::Gain::mv_80, 4);
        */
    }

    static void checkPower() {
        uint16_t iTotal = iSenseTotal_.current();
        /*
        uint16_t iML = iSenseML_.current();
        uint16_t iMR = iSenseMR_.current();
        */
    }

    static void activate() {

    }

    static void deactivate() {
        //feedback_.device.setActive(false);
        // TODO do stuff fere
        //setMotorL(channel::Motor::Control::Coast());
        //setMotorR(channel::Motor::Control::Coast());
        // TODO turn off the rest

    }

    //@}

    /** \name Radio comms
     
        
     */
    //@{
    static inline NRF24L01 radio_{NRF_CS_PIN, NRF_RXTX_PIN};
    static inline bool transmitting_ = false;
    static inline uint8_t rxBuffer_[32];
    static inline uint8_t txBuffer_[32];
    static inline uint8_t errorBuffer_[32];
    static inline uint8_t errorIndex_; 
    static inline uint8_t * response_;
    static inline uint8_t responseTimeout_ = 0;
    static inline uint16_t connTimeout_ = 0;
    static inline uint8_t controller_[] = { 0, 0, 0, 0, 0};
    static inline uint16_t deviceId_;
    static inline char deviceName_[16];

    /** Initializes the radio and enters the receiver mode.
     */
    static bool initializeRadio() {
        if (!radio_.initialize(msg::DefaultAddress, msg::DefaultAddress, msg::DefaultChannel))
            return false;
        radio_.standby();
        radio_.enableReceiver();
        errorBuffer_[0] = msg::Error::ID;
        deviceId_ = 12345;
        memcpy(deviceName_, "LegoRemote", 11);
        return true;
    }

    static bool paired() { return controller_[0] != 0; }

    static bool connected() { return controller_[0] != 0 && ! feedback_.device.connectionLost(); }

    static bool isPairedController(uint8_t const * name) {
        if (controller_[0] == 0)
            return false;
        for (uint8_t i = 0; i < 5; ++i)
            if (controller_[i] != name[i])
                return false;
        return true;
    }

    static void error(msg::ErrorKind err, uint8_t data = 0) {
        errorBuffer_[errorIndex_++] = static_cast<uint8_t>(err);
        errorBuffer_[errorIndex_++] = data;
        // tentatively write the end of error info after this one 
        if (errorIndex_ < 32)
            errorBuffer_[errorIndex_] = 0; 
    } 

    /** Receive command, process it and optionally send a reply.
     */
    static void radioIrq() {
        
        if (transmitting_) {
            radio_.clearIrq();
            NRF24L01::FifoStatus fifo = radio_.getFifoStatus();
            if (fifo.txEmpty()) {
                radio_.standby();
                radio_.enableReceiver();
                transmitting_ = false;
                // if the rx fifo is empty, we can quit immediately and will be notified of the next message by the IRQ, otherwise if there is something continue to the receive check and message processing to ensure the message will be processes (the IRQ is lost by the above clear action)
                if (fifo.rxEmpty())
                    return;
            } else {
                return;
            }
        } else {
            radio_.clearDataReadyIrq();
        }
        // try processing the message, if any
        if  (radio_.receive(rxBuffer_, 32)) {
#if (defined DEBUG_OLED)
            ++rx_;
#endif
            // set the response to txBuffer and load with NOP message (which we won't transmit if not changed)
            txBuffer_[0] = msg::Nop::ID;
            response_ = txBuffer_;
            // reset the error size so that we know whether to send it or not
            errorIndex_ = 1;
            if (!paired() && rxBuffer_[0] > msg::Pair::ID) {
                error(msg::ErrorKind::DeviceNotPaired, rxBuffer_[0]);
            } else {
                switch (rxBuffer_[0]) {
                    // set the tx address to the one provided in the request and then send the information 
                    case msg::RequestDeviceInfo::ID: {
                        // TODO add a random delay(?)
                        cpu::delayMs(100);
                        uint8_t * name = reinterpret_cast<msg::RequestDeviceInfo const *>(rxBuffer_)->controllerAddress;
                        if (!connected() || isPairedController(name)) {
                            radio_.setTxAddress(name);
                            new (txBuffer_) msg::DeviceInfo{LegoRemote::NUM_CHANNELS, deviceId_, deviceName_};
                        } 
                        break;
                    }
                    // reset the rx and tx addresses to default and clear the pairing flag
                    case msg::Reset::ID: {
                        uint8_t * name = reinterpret_cast<msg::Reset const *>(rxBuffer_)->controllerAddress;
                        if (!paired() || isPairedController(name)) {
                            radio_.initialize(msg::DefaultAddress, msg::DefaultAddress, msg::DefaultChannel);
                            radio_.standby();
                            radio_.enableReceiver();
                            controller_[0] = 0; // clear pairing info
                        }
                        break;
                    }
                    // pairs the device with the controller, sets the rx and tx addresses accordingly and updates the channel as requested 
                    case msg::Pair::ID: {
                        msg::Pair const * msg = reinterpret_cast<msg::Pair const *>(rxBuffer_);
                        if (msg->deviceId == deviceId_ && (strncmp(msg->deviceName, deviceName_, 15) == 0)) {
                            if (!connected() || isPairedController(msg->controllerAddress)) {
                                radio_.initialize(msg->deviceAddress, msg->controllerAddress, msg->channel);
                                radio_.standby();
                                radio_.enableReceiver();
                                // and enter the paired mode
                                for (uint8_t i = 0; i < 5; ++i)
                                    controller_[i] = msg->controllerAddress[i];
                            }
                        } 
                        // leave response at NOP
                        break;
                    }
                    // returns the channel information. This is a bit silly as we do not store the whole 32 bytes in the channel info, but we don't care if we send garbage after the final 0
                    case msg::GetChannelInfo::ID:
                        response_ = LegoRemote::CHANNEL_INFO;
                        break;
                    // returns the channel configuration for the provided channel number
                    case msg::GetChannelConfig::ID:
                        getChannelConfig(reinterpret_cast<msg::GetChannelConfig const *>(rxBuffer_)->channel);
                        break;
                    // sets the channel config for given channel    
                    case msg::SetChannelConfig::ID: {
                        msg::SetChannelConfig const * msg = reinterpret_cast<msg::SetChannelConfig const *>(rxBuffer_);
                        setChannelConfig(msg->channel, msg->config);
                        response_ = reinterpret_cast<uint8_t const *>(&feedback_);
                        break;
                    }
                    // returns the channel control for the provided channel number
                    case msg::GetChannelControl::ID:
                        getChannelControl(reinterpret_cast<msg::GetChannelControl const *>(rxBuffer_)->channel);
                        break;
                    // sets channel control for specific channels
                    case msg::SetChannelControl::ID: {
                        uint8_t i = 1;
                        while (rxBuffer_[i] != 0) {
                            uint8_t channelIndex = rxBuffer_[i++];
                            i += setChannelControl(channelIndex, rxBuffer_ + i);

                        }
                        break;
                    }
                    case msg::SetControlConsecutive::ID: {
                        msg::SetControlConsecutive const * msg = reinterpret_cast<msg::SetControlConsecutive const *>(rxBuffer_);
                        uint8_t i = 0;
                        for (uint8_t channel = msg->fromChannel, echannel = msg->fromChannel + msg->numChannels; ++channel; channel != echannel)
                           i += setChannelControl(channel, msg->data + i);
                        break; 
                    }

                    // returns feedback for the given channel
                    case msg::GetChannelFeedback::ID: 
                        getChannelFeedback(reinterpret_cast<msg::GetChannelFeedback const *>(rxBuffer_)->channel);
                        break;
                    default:    
                        error(msg::ErrorKind::InvalidCommand, rxBuffer_[0]);
                        break;
                }
                if (errorIndex_ > 1 || response_[0] != msg::Nop::ID)
                    responseTimeout_ = 7;
            }
            // reset the connection timeout
            if (connected())
                connTimeout_ = CONNECTION_TIMEOUT;
        }
    }

    static void radioResponse() {
        // send the optional error and feedback back to keep the comms
        if (errorIndex_ > 1 || response_[0] != msg::Nop::ID) {
            radio_.standby();
            if (errorIndex_ > 1) {
                radio_.transmit(errorBuffer_, 32);
#if (defined DEBUG_OLED)
                ++tx_;
#endif
            }
            if (response_[0] != msg::Nop::ID) {
                radio_.transmit(response_, 32);
#if (defined DEBUG_OLED)
                ++tx_;
#endif
            }
            transmitting_ = true;
            radio_.enableTransmitter();
        }
    }

    /** Loss of connection event. 
     */
    static void connectionLost() {
        deactivate();
        feedback_.device.setConnectionLost();
        connTimeout_ = CONNECTION_RESET;
    }

    //@}

    /** \name Channels
     
     */
    //@{


    static inline Channel<channel::Motor> ml_;
    static inline Channel<channel::Motor> mr_;
    static inline Channel<channel::CustomIO> l1_;
    static inline Channel<channel::CustomIO> r1_;
    static inline Channel<channel::CustomIO> l2_;
    static inline Channel<channel::CustomIO> r2_;
    static inline Channel<channel::ToneEffect> tone_;
    static inline Channel<channel::RGBStrip> rgb_;

    /** Feedback for all channels. 
     */
    static inline LegoRemote::Feedback feedback_;

    template<typename T>
    static void getChannelDataFrom(channel::Kind kind, T const & config) {
        txBuffer_[1] = static_cast<uint8_t>(kind);
        memcpy(txBuffer_ + 2, & config, sizeof(T));
    }
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
void loop() {
    Remote::loop();
}

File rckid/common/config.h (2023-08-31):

/** \file Configuration 

  
*/

#define HEART_SIZE_SECONDS 600 
#define HEARTS_LOW_THRESHOLD 600



// note this is also in retroarch directory
#define SCREENSHOT_TMP_DIRECTORY "/rckid/.rckid/tmp/screenshots"

/** \section Input Controls
 
    
 */

#define LIBEVDEV_GAMEPAD_NAME "rckid-gamepad"

#define BTN_HOME_POWERON_PRESS 400

#define BTN_HOME_POWEROFF_PRESS 800

#define DEFAULT_RUMBLER_STRENGTH 64

#define CHARGING_COLOR Color::RGB(0, 64, 0)

#define ANALOG_BUTTON_THRESHOLD 48

/** Debounce interval for the buttons on RPI side in ticks (10ms). 
 */
#define BTN_DEBOUNCE_DURATION_TICKS 2

/** \section UI 
 */

#define FORCE_FULL_REDRAW false
//#define RENDERING_STATS
//#define RENDERING_STATS_DETAILED
#define RENDERING_STATS_FPS

#define BACKGROUND_OPACITY 0.3
#define GAME_PLAYER_BACKGROUND_OPACITY 128
#define VIDEO_PLAYER_BACKGROUND_OPACITY 128

#define WIDGET_FADE_TIME 250

/** \section Audio 

    Audio volume can be set in range from 0 to 100%, which is recalculated to log/exp scale via the amixer. Min value is always 0 (mute). Max value and the step, as well as the initial power-on value can be set here.  
 */
#define AUDIO_MAX_VOLUME 100
#define AUDIO_DEFAULT_VOLUME 50
#define AUDIO_VOLUME_STEP 10

#define AUDIO_MUSIC_ARTWORK_DIR "/rckid/images/music artwork"

/** \section Device Build Configuration 
 
    The following settings can enable or disable certain features based on the option RCKid hardware being present or not. 
 */

/** Determines whether the thumbstick has button capability. Switch joysticks do, PSP joysticks don't. When disabled, the libevdev gamepad device will not support the BTN_JOYSTICK key. 
*/
#define ENABLE_THUMBSTICK_BUTTON 1

/** \section Comms and timeouts
 */

/** I2C address of the AVR chip. Fully configurable, but this is a nice number. 
 */
#define AVR_I2C_ADDRESS 0x43

/** Size of the receive I2C buffer on the AVR side. The maximum size of any command. It onl has real effect on the AVR where memory is at premium. The Rpi can and will abuse this number.   
 */
#define I2C_BUFFER_SIZE 32


/** The AVR IRQ communication pin on the RPI side. Used by both the rckid and programmer.
 */
#define RPI_PIN_AVR_IRQ 25

/** AVR IRQ comms pin on the AVR side (used by the rckid and the bootloader). */
#define AVR_PIN_AVR_IRQ 10

/** AVR Pin for the backlight control (used by the rckid and the bootloade). */
#define AVR_PIN_BACKLIGHT 9

/** RPi power up timeout in ticks 
 */
#define RPI_POWERUP_TIMEOUT 6000

/** RPi powerdown in ticks
 */
#define RPI_POWERDOWN_TIMEOUT 6000

/** RPi ping timeout.
 */
#define RPI_PING_TIMEOUT 10000

/** \section Power & Voltage 
  
 */

/** When battery voltage reaches this threshold, we enter the PowerDown mode immediately. Must be at least 3V3 for RPi's correct operation. Setting it higher will make the system a bit more stable. When critical battery reached, RCkid won't start until charged above the BATTERY_THRESHOLD_CHARGED voltage. 
 */
#define BATTERY_THRESHOLD_CRITICAL 330

/** When the battery/vcc voltage goes above the battery charged threshold (i.e. either running on USB power or charged enough while sleeping), the critical battery flag is reset allowing RPi to boot. 
 */
#define BATTERY_THRESHOLD_CHARGED 370

/** When battery is below this threshold a low battery warning is displayed. 
 */
#define BATTERY_THRESHOLD_LOW 340

/** When VCC is above this value (set to be greater than that produced by Li-Ion battery, but lower than 5V to account for voltage drop) we can assume that we are running from the USB power. */
#define VCC_THRESHOLD_VUSB 440


/** \section Walkie-Talkie
*/

#define WALKIE_TALKIE_HEARTBEAT_INTERVAL_MIN 300
#define WALKIE_TALKIE_HEARTBEAT_INTERVAL_MAX 500
#define WALKIE_TALKIE_STORE_PTT 

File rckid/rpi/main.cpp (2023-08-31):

#ifdef ARCH_RPI
#include "bcm_host.h"

struct DispmanXBackgroundLayer {
    int32_t layer;
    DISPMANX_RESOURCE_HANDLE_T resource;
    DISPMANX_ELEMENT_HANDLE_T element;
};

#endif

#include <unordered_map>
#include <filesystem>

#include "raylib_wrapper.h"

#include "platform/platform.h"

#include "rckid.h"
#include "window.h"
#include "pixel_editor.h"
#include "debug_view.h"
#include "keyboard.h"
#include "game_player.h"
#include "music_player.h"
#include "video_player.h"
#include "torchlight.h"
#include "recorder.h"
#include "walkie_talkie.h"
#include "remote.h"
#include "nrf_sniffer.h"
#include "carousel_json.h"
#include "carousel_dir.h"
#include "gauge.h"
#include "external_app.h"

#include "menu.h"

void printLogLevel(int logLevel, std::ostream & s) {
    switch (logLevel) {
        case LOG_TRACE:
            s << "TRACE";
            break;
        case LOG_DEBUG:
            s << "DEBUG";
            break;
        case LOG_INFO:
            s << "INFO";
            break;
        case LOG_WARNING:
            s << "WARNING";
            break;
        case LOG_ERROR:
            s << "ERROR";
            break;
        case LOG_FATAL:
            s << "FATAL";
            break;
        default:
            s << "??? (" << logLevel << ")";
            break;
    }
}

void logCallback(int logLevel, const char * text, va_list args) {
    static std::ofstream logFile{"/rckid/log.txt"};
    static size_t bufferSize = 1024;
    static char * buffer = new char[bufferSize];
    int len = vsnprintf(buffer, bufferSize, text, args);
    if (len >= bufferSize) {
        bufferSize = len + 1;
        delete [] buffer;
        buffer = new char[bufferSize];
        len = vsnprintf(buffer, bufferSize, text, args);
    }
    if (len >= 0) {
        buffer[len] = '\0';
#ifndef NDEBUG
        printLogLevel(logLevel, std::cout);
        std::cout << ": " << buffer << std::endl;
#endif
        printLogLevel(logLevel, logFile);
        logFile << ": " << buffer << std::endl;
        logFile.flush();
    }
}

class Widgets {
public:
    Widgets() {
        w_["games"] = new GameBrowser("/rckid/games");
        w_["video"] = new VideoBrowser("/rckid/videos");
        w_["music"] = new MusicBrowser("/rckid/music");
        w_["remote"] = new Remote{};
        w_["walkie-talkie"] = new WalkieTalkie{};
        w_["torchlight"] = new Torchlight{};
        w_["paint"] = new PixelEditor{};
        w_["baby-monitor"] = nullptr;
        w_["recorder"] = new Recorder{};
        w_["nrf-sniffer"] = new NRFSniffer{};
        w_["file-explorer"] = new FileExplorer{"/rckid"};
        w_["external-app"] = new ExternalApp{};
    }

    ~Widgets() {
        for (auto i : w_)
            delete i.second;
    }

    void start(std::string const & widgetName) {
        auto i = w_.find(widgetName);
        if (i != w_.end() && i->second != nullptr) {
            window().showWidget(i->second);
        } else {
            // TODO unknown or unimplemented widget
        }
    }
private:

    std::unordered_map<std::string, Widget *> w_;


}; // Widgets


/** Main RCKid app. 
 
 */
int main(int argc, char * argv[]) {
    // ensure the required paths
    std::filesystem::create_directories(AUDIO_MUSIC_ARTWORK_DIR);
    std::filesystem::create_directories("/rckid/images/screenshots/games");
    std::filesystem::create_directories("/rckid/images/screenshots/video");
    std::filesystem::create_directories(SCREENSHOT_TMP_DIRECTORY);
    system("cp /rckid/log.txt /rckid/log.old.txt");
    SetTraceLogLevel(LOG_ALL);
    SetTraceLogCallback(logCallback);
#ifdef ARCH_RPI
    // make sure that we have the rights to add uinput device    
    system("sudo chown pi /dev/uinput");
    // add layer 0 black rectangle to block framebuffer, we don't care about errors,
    // TODO Maybe add some nice picture
    bcm_host_init();
    DISPMANX_DISPLAY_HANDLE_T display = vc_dispmanx_display_open(0);
    DISPMANX_RESOURCE_HANDLE_T resource;
    DISPMANX_ELEMENT_HANDLE_T element;
    // init bg layer
    {
        VC_IMAGE_TYPE_T type = VC_IMAGE_RGBA16;
        uint32_t vc_image_ptr;
        resource = vc_dispmanx_resource_create(type, 1, 1, &vc_image_ptr);
        VC_RECT_T dst_rect;
        vc_dispmanx_rect_set(&dst_rect, 0, 0, 1, 1);
        uint16_t color = 0x000f; // black
        vc_dispmanx_resource_write_data(resource, type, sizeof(color), &color, &dst_rect);
    }
    // draw the bg layer 
    {
        DISPMANX_UPDATE_HANDLE_T update = vc_dispmanx_update_start(0);    
        VC_DISPMANX_ALPHA_T alpha = { DISPMANX_FLAGS_ALPHA_FROM_SOURCE, 255, 0 };
        VC_RECT_T src_rect;
        vc_dispmanx_rect_set(&src_rect, 0, 0, 1, 1);
        VC_RECT_T dst_rect;
        vc_dispmanx_rect_set(&dst_rect, 0, 0, 0, 0);
        element = vc_dispmanx_element_add(
            update,
            display,
            0, // layer
            &dst_rect,
            resource,
            &src_rect,
            DISPMANX_PROTECTION_NONE,
            &alpha,
            nullptr,
            DISPMANX_NO_ROTATE);
        vc_dispmanx_update_submit_sync(update);
    }
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

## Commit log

2022-01-05 Some stuff.
    Can blink led, can talk serial, can talk i2c. Some datasheets and some plan, sort of.
2022-01-10 SPI, basic nrf24l01 ported.
    Some initial work on crossplatform platform. Initial work on display, pio added to build.
2022-01-11 SPI & platform base supports ATTiny3216 and arduino.
    Added NRF24l01 transmitter and receiver for range checking. Not working though, only sends the first packet after reset.
2022-01-13 HW inits, towards remote uploads
    [case.skp]
2022-01-14 platformio setup for pico and attiny via rpi.
    Seems like pico is sending stuff, but failing to get acks...
2022-01-24 Displays and connectors
2022-01-27 Can show stuff on display via SPI.
2022-01-28 Some very basic DMA seems to be sort of working.
2022-01-28 Parallel display works, no DMA.
2022-01-30 Basic pixel and MPU6050 + i2c for rpio.
2022-01-30 DMA canvas fill, canvas coords rotation. Pinout.
2022-02-02 AVR project, I2C comms between the two.
2022-02-05 automated pico programming via usb
2022-02-07 tiny can turn pico off
2022-03-05 PCB and case draft
    [case2.skp]
2022-03-30 Switched to RPi zero based version.
2022-04-01 Sync, added I2C and gpio
2022-04-02 ABXY buttons test.
2022-04-03 More gamepad buttons, I2C integrated, MPU6050 queried.
2022-04-09 Platform rewrite for cleaner code and in preparation for spi support on rpi.
2022-04-10 SPI in platform for rpi draft.
2022-04-28 I2C for tiny series 1.
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2022-05-08 TCD basic setup for motor H-bridge PWM. Neopixels update bug fixed.
    [lego-remote.cpp]
2022-06-05 HW schematics & pcbs update, more HW drawings.
    [case.skp, case2.skp, rcboy.skp]
2022-06-28 HW updates
    [rcboy.skp]
2022-07-09 Added BOM, updated TODO. PCB for rcboy almost finished.
2022-07-10 TODO & pcb updates.
2022-07-15 backlight and motor switched to arduino pwm via TCA0.
    Tick at 100Hz. Real CPU freq determined.
2022-07-16 Some I2C debugging from rpi
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2022-08-10 framed pcb as manufactured
2022-08-13 Refactoring, single app gui and gamepad.
    [case.skp, case2.skp, rcboy.skp]
2022-08-26 AVR buttons working, rpi buttons working. AVR RPI comms working. Accel can be read. joystick axes can be read.
2022-08-27 Some playing with QT. Shoulder button backs enlarged.
2022-08-28 Headphones detection working (pullup on the rpi input pin disabled). Works for 2.5V too.
2022-09-19 Some updtes to HW, driver calibration for rpi buttons.
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2022-09-28 Updated, unchecked pcb version. More code in rpi.
2022-10-08 Animations in menu. No longer using qt rc.
    [carousel.h, gui.h, main.cpp]
2022-10-10 better SD image
    [config.txt]
2022-10-10 And some more SD info added.
    [config.txt]
2022-10-27 Some updtes. PCB should be final-ish
2022-10-30 udev rules fixed for gamepad detection
    [gui.h]
2022-10-30 Joycon and PSP1000 joysticks in single board
2022-11-06 Power menu can be entered with lVol + rVol
2023-01-04 AVR I2C bootloader does nothing but compiles.
2023-01-05 Updates to TODO, gpio-poweroff will work with extra pin
2023-01-05 Some support for audio recording in both avr and rpi. Fixes to debug info mode.
    [comms.h, gamepad.cpp, main.cpp]
2023-01-06 Started work on I2C programmer
2023-01-20 I2C Bootloader should be done
2023-01-20 Fixed bootloader fuses. Updated PCB
2023-01-21 I2C Bootloader & programmer seems to be working.
2023-01-22 Bootloader updater, avr app does check too. Simpler building.
    [config.txt]
2023-01-23 Thumbstick with bent cable attempt
2023-02-03 raylib rpi driver comms
2023-02-05 wiringPi gpio and I2C ioctl working
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2023-02-05 All comms working
    [config.txt]
2023-02-25 Towards vertical layout
    [config.txt]
2023-03-11 Cleanup for rckid & vertical layout
    [case.skp, case2.skp, rcboy.skp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]
2023-03-12 Some more thoughts on AVR.
    Different pinout & AVR code organization attempt. AVR clock speeds seem to be fixed.
    [comms.h, config.h]
2023-03-13 PWM works, analog buttons work. Neopixel works a bit, stays on 1,1,1 when told to be black.
2023-03-14 BTN_HOME interrupt is working.
2023-03-15 Started playing with poweroff
2023-03-20 Started writing the AVR remote, this time with correct timings.
    [lego-remote.cpp]
2023-03-24 Fixed JOY connector, updates to lego-remote test setup.
    [lego-remote.cpp]
2023-03-26 Some more to AVR & RPi pinout fixed
    [comms.h, rckid.cpp, rckid.h]
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2023-04-09 raylib mock keys at the rckid driver level.
2023-04-21 Started with assembly guide
2023-04-29 Debug info shows all buttons
2023-05-05 State moved to rckid driver
2023-05-05 StopRendering whle drawing fixed.
    [carousel.h, keyboard.h, main.cpp]
2023-05-08 config test
    [config.txt]
2023-05-09 Keyboard fixes, kms driver cmake
    [keyboard.h, main.cpp, rckid.h]
2023-05-09 changes to config.txt
    [config.txt]
2023-05-11 Can control VLC. Framebuffer no longer visible.
    [config.h, main.cpp, rckid.cpp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]
2023-05-12 Latest icon assets, fixed background and game menus. Minor others.
    [rckid-gamepad.cfg, retroarch.cfg]
2023-05-14 SD card updates
    [retroarch.cfg]
2023-05-15 Config restructured, hotkeys enabled.
    [rckid-gamepad.cfg, retroarch-core-options.cfg, retroarch.cfg]
2023-05-15 Old configs removed
    [rckid-gamepad.cfg, retroarch.cfg]
2023-05-16 Controls do work a bit in games as well.
    [rckid-gamepad.cfg, retroarch.cfg]
2023-05-22 Fixed bootloader BTN_HOME check pin.
2023-05-23 Buttons & brightness fixed.
    [comms.h]
2023-05-25 Home button power off & on works
2023-05-26 Torchlight commands. Removed splashscreen for faster boot. LED still not working.
    [comms.h, main.cpp, rckid.h]
2023-05-28 dosbox as emulator (not working yet)
    [main.cpp, rckid.cpp]
2023-05-30 Power timeout at initial power on fixed-ish, but still broken ui
    [main.cpp, rckid.cpp]
2023-06-09 Some more stats printed out
2023-06-14 PCB v 3.2 almost done
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2023-06-14 "debouncing" VCC so that we can switch VBATT & VCC
2023-06-17 Graphics works again with games and videos as well.
    No frames are rendered while in games. Some thoughts on the remote protocol.
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2023-06-27 Mic recording fixed on AVR. Incomplete batch flag moved to status.
    [comms.h, rckid.cpp, rckid.h]
2023-06-29 Device ping does not repeat last command (made the Rpi to go to powerdown immediately every second poweron)
2023-07-01 I2C ping does not set the ready flag
2023-07-02 Fixed AVR power on mode
    [rckid.cpp]
2023-07-03 Mock input events fixed.
    [rckid.cpp]
2023-07-06 Ms and us delays switched to RTC
2023-07-06 Delays switched to avr delay loops & other minor changes.
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2023-07-09 Recording no longer done by closure callback
    [rckid.cpp, rckid.h]
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2023-07-18 Pairing updated to specify which device as well.
2023-07-21 Some work towards canvas, which may not be needed and reworked carousels, which will definitely be needed.
    [canvas.h]
2023-07-22 Refactoring: singletons will die
2023-07-24 Some BOM, modal widgets drafting
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2023-07-30 Proper rckid threads shutdown to prevent double delete in hwLoop. All textures rendered by canvas.
    [canvas.h, carousel.h, music_player.h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]
2023-08-06 locking rckid driver draft
2023-08-07 Raylib wrapper likely fixed
    [canvas.h, main.cpp, rckid.cpp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]
2023-08-08 avr pins & button detection updated
2023-08-16 Code updated to v 3.3 most systems tested for basic working
    [rckid-top-plate.dxf, rckid.skp]
2023-08-16 plate updated
    [rckid-top-plate.dxf]
2023-08-17 Battery & charging redesigned in rpi
    [comms.h, rckid.cpp]
2023-08-18 AVR charging seems to work right
    [rckid-top-plate.dxf]
2023-08-19 Accelerometer and joystick can in theory act as own buttons
2023-08-19 thumbstick can be used as buttons
2023-08-22 Games save screenshots. Walkie talkie can set volume with arrows
    [rckid-gamepad.cfg, retroarch.cfg]
2023-08-23 Top plate pexiglass fixed for 0.3mm cut width
    [rckid-top-plate.dxf]
2023-09-05 Game menu redesigned for single use slot and latest game slot
